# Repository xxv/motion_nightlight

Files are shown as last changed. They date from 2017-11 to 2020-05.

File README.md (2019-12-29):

Motion detector night light
===========================

A light to illuminate your dark hallway on your way to the bathroom.

Ingredients
-----------

### Custom parts
* fully-populated and assembled PCB
* laser-cut wooden housing (`housing/housing_lasercut.scad`), cut from 3mm plywood
* laser-cut or 3D printed front grate (`housing/front_grate.svg`), 1.5mm black acrylic
* laser-cut diffuser holder (`housing/diffuser_holder.scad`), cut from 3mm black acrylic
* 3D printed board holder (`housing/board_holder.scad`)
* 3D printed battery plate (`housing/battery_plate.scad`)

### Vitamins
* 2x M2.5x8 black flat head bolt with washer and nut McMaster: 91294A016,
  90591A270, 93475a196
* 10x M2.2 6.5mm round head screws for sheet metal McMaster: 94997a125
* 3x AA batteries

### Other bits
* Diffuser (`housing/diffuser.scad`) cut from LEE Filters 810 Zircon Diffusion
  1 (or similar)
* Wood glue (+ [clamps](https://github.com/xxv/corner-clamp))
* Super glue
* 2mm-wide double-stick tape or similar

Main Assembly
-------------

1. Assemble PCB. Use M2.5x8 hardware to fasten battery holder to board.
2. Assemble diffuser assembly (see below).
3. Cut out main enclosure.
4. Glue main enclosure together with wood glue. Clamp and wipe off excess glue
   with a damp paper towel.
5. Glue battery plate to battery cover with super glue. (center carefully)
6. Once main enclosure glue is dry, screw board holder to it with M2.2 screws.
7. Screw board to board holder using M2.2 screws.
8. Slide the diffuser assembly into place. It should fit snugly, but not fall out.
9. Put fresh batteries into the night light. Don't put the battery cover on yet.
10. Calibrate the ambient light sensor.
    1. Bringing the night light into a dark room.
    2. Pull out the middle battery.
    3. Holding down both buttons, re-insert the middle battery.
    4. The status LED should blink three times to indicate that the calibration has been saved.

Diffuser Assembly
-----------------

1. Cut out the diffuser stand (4 identical parts) and assemble with super glue.
2. Cut out the diffuser from the Zircon 810 sheet using the diffuser template.
   This material is polyester and can be laser cut if desired.
3. Adhere the diffuser to the diffuser stand using the double-stick tape.
4. Cut out the diffuser decorative grate `front_grate.svg`. Note the
   non-commercial terms for this part in the license at the bottom.
5. Adhere the diffuser decorative grate to the diffuser using 2mm double-stick tape.

License
-------

* The PCB design and associated firmware are licensed under the GPLv3.
* The diffuser grate artwork (`front_grate.svg` and derivatives) is licensed under
  the Creative Commons CC-BY-NC-SA 4.0. If you wish to sell night lights using
  these files, you must use your own design for this one part. Consider this an
  opportunity to make your night light truly your own!
* All of the mechanical parts (housing, board stand, etc.) are available
  licensed under the Creative Commons CC-BY-SA 4.0 license.

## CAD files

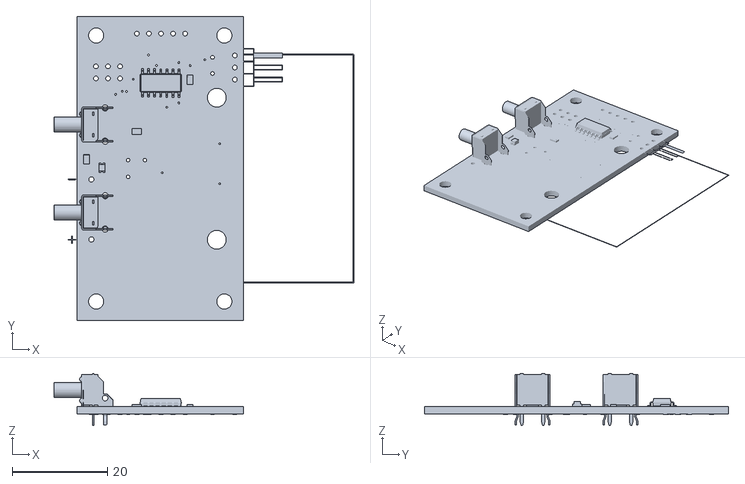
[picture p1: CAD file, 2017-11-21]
board/motion_light.stl
63.1 x 64.0 x 11.0

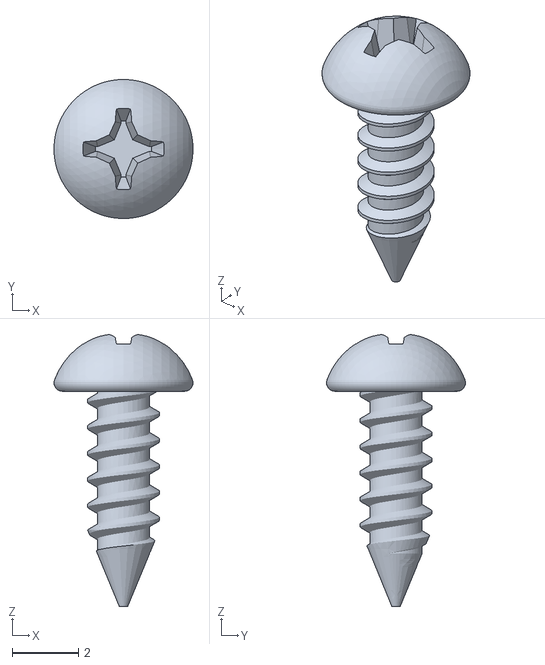
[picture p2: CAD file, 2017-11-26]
housing/m2.2_wood_screw.stl
4.20 x 4.20 x 8.22

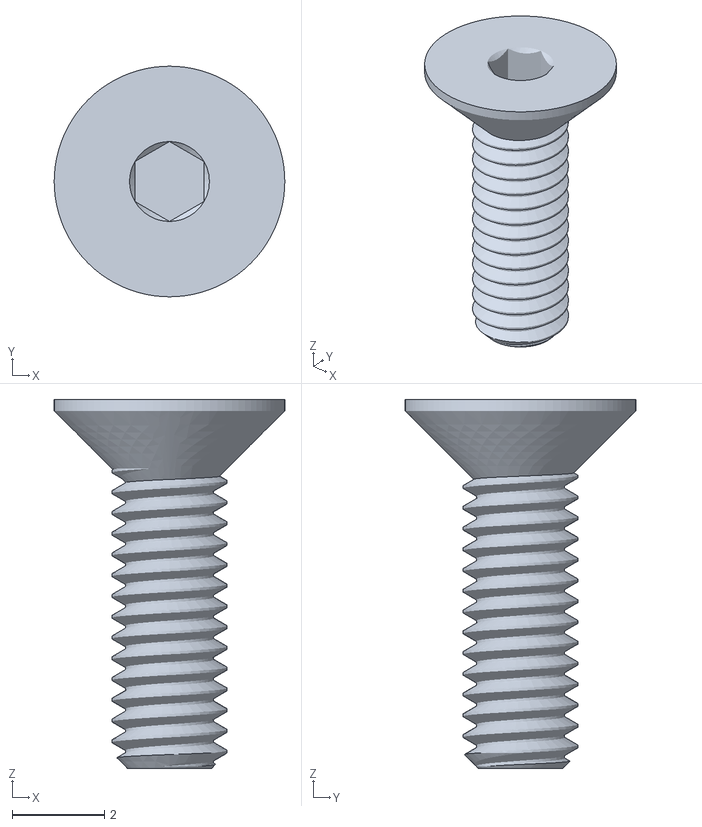
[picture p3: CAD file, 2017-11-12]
housing/m2.5x8_screw.stl
5.00 x 5.00 x 8.00

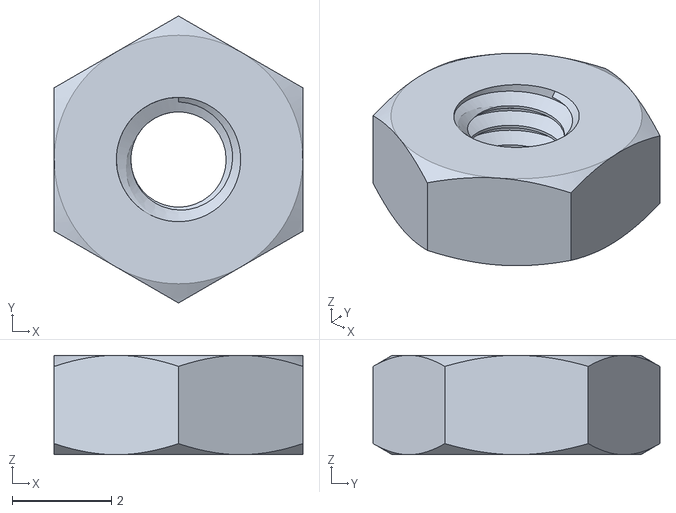
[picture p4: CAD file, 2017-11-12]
housing/m2.5_nut.stl
5.00 x 5.77 x 2.00

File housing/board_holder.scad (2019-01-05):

include <motion_nightlight_housing.scad>;

board_holder(interior_battery);

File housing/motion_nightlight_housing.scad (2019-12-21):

include <boxmaker.scad>;

$fn = 120;
smidge = 0.1;

// main interior volume
interior_battery = [94, 94, 32];
// thickness of the wall material
wall_size = 3.3;
// distance between the top and the board
board_z = 12.5;

// size of the PCB
board_size = [64, 35.0, 1.6];
// Clearance from the wall for the board
board_clearance = 1;
// distance in from the edge of the PCB that the holes are
board_hole_offset = 4;

battery_hole_size = [46, 55];
battery_hole_offset = [0, 3];
battery_finger_size = 15;
// holes to screw plate into the wood
laser_pilot_hole = 1.2/2;

// amount that the board mount overlaps with the wood
overlap = 6;
// how much inset the battery lid rest is from the battery hole
inset = 1;

// width of the plate holding the board
plate_width = board_size[0] + overlap * 2;
// Wood screws that mount the plate to the bottom wall
wood_screws = [
  [battery_hole_size[0]/2 + overlap/2, board_clearance + board_size[1] + overlap/2, 0],
  [battery_hole_size[0]/2 + overlap/2, battery_hole_size[1] + battery_hole_offset[1] + overlap/2, 0],
  [plate_width/2 - overlap/2, overlap/2, 0]
  ];

diffuser_stand_volume = interior_battery;

stand_material = 3;

//////////////////////////////////////////////////////////////////////

*mockup(interior_battery, diffuser_stand_volume, battery_present=1);

/********* laser cut *********/
*enclosure_2d(interior_battery, wall_size);

/********* 3D Print **********/
*board_holder(interior_battery);
*battery_plate(interior_battery);
*grate();
*diffuser_stand_print(diffuser_stand_volume);
  // This can be a knife template for cutting the diffuser material
*diffuser(diffuser_stand_volume, 2);

//////////////////////////////////////////////////////////////////////

module mockup(interior, stand_volume, battery_present) {
  translate([interior[0]/2 - board_size[0]/2, board_clearance, 0])
    electronics(battery_present);
  enclosure_with_design(interior, stand_volume);
}

module diffuser_stand_print(stand_volume) {
  spacing = 1;

  diffuser_stand_leg([stand_volume.x, stand_volume.z], stand_material);
  translate([0, 1 * (stand_volume.z + spacing)])
      diffuser_stand_leg([stand_volume.x, stand_volume.z], stand_material);

  translate([0, 2 * (stand_volume.z + spacing)])
    diffuser_stand_leg([stand_volume.y, stand_volume.z], stand_material);

  translate([0, 3 * (stand_volume.z + spacing)])
    diffuser_stand_leg([stand_volume.y, stand_volume.z], stand_material);
}

module enclosure_with_design(interior, stand_volume) {
  translate([0, 0, -(interior[2] - board_z)]) {
    translate([0, 0, stand_volume[2]])
      diffuser_and_grate(stand_volume);

    color([0.5, 0.5, 0.5]) {
      board_holder(interior);
      battery_plate(interior);
    }

    color("SaddleBrown", alpha=1)
      enclosure_3d(interior, wall_size);
  }
}

module diffuser_and_grate(inner_size) {
  diffuser_thickness = 0.1;

  translate([0, 0, diffuser_thickness + 0.01])
    color(c=[0.2, 0.2, 0.2])
      grate();

  // diffuser
  color(c=[0.95, 0.95, 0.95, 1])
    diffuser(inner_size, diffuser_thickness);

  color(c=[0.2, 0.2, 0.2])
      diffuser_stand(inner_size);
}

module diffuser_stand(inner_size) {
  material = stand_material;

  rotate([-90, 0, 0])
    linear_extrude(height=material)
      diffuser_stand_leg([inner_size.x, inner_size.z], material);

  translate([0, inner_size.y, 0])
    rotate([-90, 0, 270])
      linear_extrude(height=material)
        diffuser_stand_leg([inner_size.y, inner_size.z], material);

  translate([inner_size.x, inner_size.y, 0])
    rotate([-90, 0, 180])
      linear_extrude(height=material)
        diffuser_stand_leg([inner_size.x, inner_size.z], material);

  translate([inner_size.x, 0, 0])
    rotate([-90, 0, 90])
      linear_extrude(height=material)
        diffuser_stand_leg([inner_size.y, inner_size.z], material);
}

module diffuser_stand_leg(bounds, material) {
  leg = 8;
  top = 5;

  difference() {
    square(bounds);
    translate([leg, top])
      square([bounds.x - leg * 2, bounds.y - top]);

    translate([0, bounds.y/3])
      square([material, bounds.y/3]);

    translate([bounds.x - material, 0])
      square([material, bounds.y/3]);

    translate([bounds.x - material, bounds.y * (2/3)])
      square([material, bounds.y/3]);
  }
}

module grate() {
  linear_extrude(height=1)
    import("front_grate.dxf");
}

module diffuser(inner_size, thickness=0.1) {
  difference() {
    cube(inner_size + [0, 0, -(inner_size[2] - thickness)]);
    translate([inner_size[0]/2, 13.5, -1])
      cylinder(r=11, h=thickness + 2);
  }
}

module board_holder(interior) {
  thickness = 1;
  stand_width = 6;
  battery_hole = [battery_hole_size[0] - inset * 2, battery_hole_size[1] - inset * 2, thickness + 1];
  board_screw_hole = 0.75;
  plate_screw_hole = 2.5;
  z_height = interior[2] - board_z - board_size[2]/2;

  screw_standoff = 2.5;

#  translate([interior[0]/2, 0, screw_standoff + 1])
      for (m = [0 : 1 : 1])
        mirror([m, 0, 0])
          for (screw = wood_screws)
            translate(screw)
              import("m2.2_wood_screw.stl");

  corner_r = overlap/2;
  overlap_rounded = overlap - corner_r;
  plate_width_rounded = plate_width - corner_r - overlap/2;

  // main plate
  intersection() {
    difference() {
      union() {
        minkowski() {
          union() {
            translate([interior[0]/2 - battery_hole_size[0]/2 - overlap_rounded, 0, 0])
              cube([battery_hole_size[0] + (overlap_rounded) * 2, battery_hole_size[1] + battery_hole_offset[1] + overlap_rounded, thickness]);

            translate([interior[0]/2 - plate_width_rounded/2, 0, 0])
              cube([plate_width_rounded, board_size[1] + board_clearance + overlap_rounded, thickness]);
            }
            cylinder(r=corner_r, h=0.0001);
        }

        // Screw stands
        translate([interior[0]/2, 0, 1])
            for (m = [0 : 1 : 1])
              mirror([m, 0, 0])
                for (screw = wood_screws)
                  translate(screw)
                    cylinder(r=overlap/2, h=screw_standoff);
      }

      // Battery hole
      translate(battery_hole_offset)
        translate([interior[0]/2 - battery_hole[0]/2, inset, -0.5])
          cube(battery_hole);

      // Screw holes
      translate([interior[0]/2, 0, -1])
        for (m = [0 : 1 : 1])
          mirror([m, 0, 0])
            for (screw = wood_screws)
              translate(screw)
                cylinder(r=plate_screw_hole/2, h=10);
    }
    cube(interior);
  }

  // board stands
  translate([interior[0]/2, board_clearance + board_size[1]/2, 0])
    for (m = [0 : 1 : 1])
      mirror([m, 0, 0])
        translate([board_size[0]/2 - stand_width - 1, -board_size[1]/2, 0])
          difference() {
            cube([stand_width, board_size[1], z_height]);

            translate([stand_width/2, board_hole_offset, z_height - 4.9])
              cylinder(r=board_screw_hole, h=5);

            translate([stand_width/2, board_size[1] - board_hole_offset, z_height - 4.9])
              cylinder(r=board_screw_hole, h=5);
          }
}

module battery_plate(interior) {
  battery_plate_wall = [3, 3, 0];
  inset_for_mating = 0.3;
  extra_inset = [inset * 2 + inset_for_mating, inset * 2 + inset_for_mating, 0];
  wall_thickness = 1.5;
  plate_thickness = 0.5;
  battery_hole = [battery_hole_size[0],
                  battery_hole_size[1],
                  wall_thickness + plate_thickness] - extra_inset;

      translate(battery_hole_offset)
        translate([interior[0]/2 - battery_hole_size[0]/2, 0, 0] + extra_inset/2)
          difference() {
            cube(battery_hole);
            translate(battery_plate_wall/2 - [0, 0, -plate_thickness])
              cube(battery_hole - (battery_plate_wall + [0, 0, -3]));
            translate([(battery_hole_size[0] - extra_inset[0])/2, battery_hole_size[1] - extra_inset[1]/2, -1])
              cylinder(d=battery_finger_size, h=wall_thickness + plate_thickness + 2);
            translate([-smidge, battery_hole.y, 0])
              rotate([10, 0, 0])
              cube([battery_hole.x + 2 * smidge, 1, battery_hole.z + 1]);
          }
}

module back_face(box_inner, thickness, tabs) {
  screw_hole_spacing = 70;
  screw_size = 3;
  screw_head_size = screw_size + 3;

  difference() {
    side_a(box_inner, thickness, tabs);
    // Battery hole
    translate(-battery_hole_offset)
      translate([box_inner[0]/2 - battery_hole_size[0]/2,
                 box_inner[1] - battery_hole_size[1]])
        difference() {
          square(battery_hole_size);

          difference() {
            translate([smidge, smidge])
              square(battery_hole_size - [smidge * 2, smidge * 2]);

              translate([battery_hole_size[0]/2, 0])
              circle(d=battery_finger_size);
          }
        }

    // Screw holes
    translate([box_inner[0]/2 - screw_hole_spacing/2, screw_head_size * 2, 0])
      rotate([180])
        screw_slot_2d(screw_head_size, screw_size, screw_head_size);
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

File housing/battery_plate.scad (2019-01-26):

include <motion_nightlight_housing.scad>;

battery_plate(interior_battery);

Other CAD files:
housing/front_grate.dxf
housing/diffuser.scad
housing/boxmaker.scad
housing/diffuser_stand.scad
housing/housing_lasercut.scad
housing/mockup.scad
housing/vertical_stand.scad

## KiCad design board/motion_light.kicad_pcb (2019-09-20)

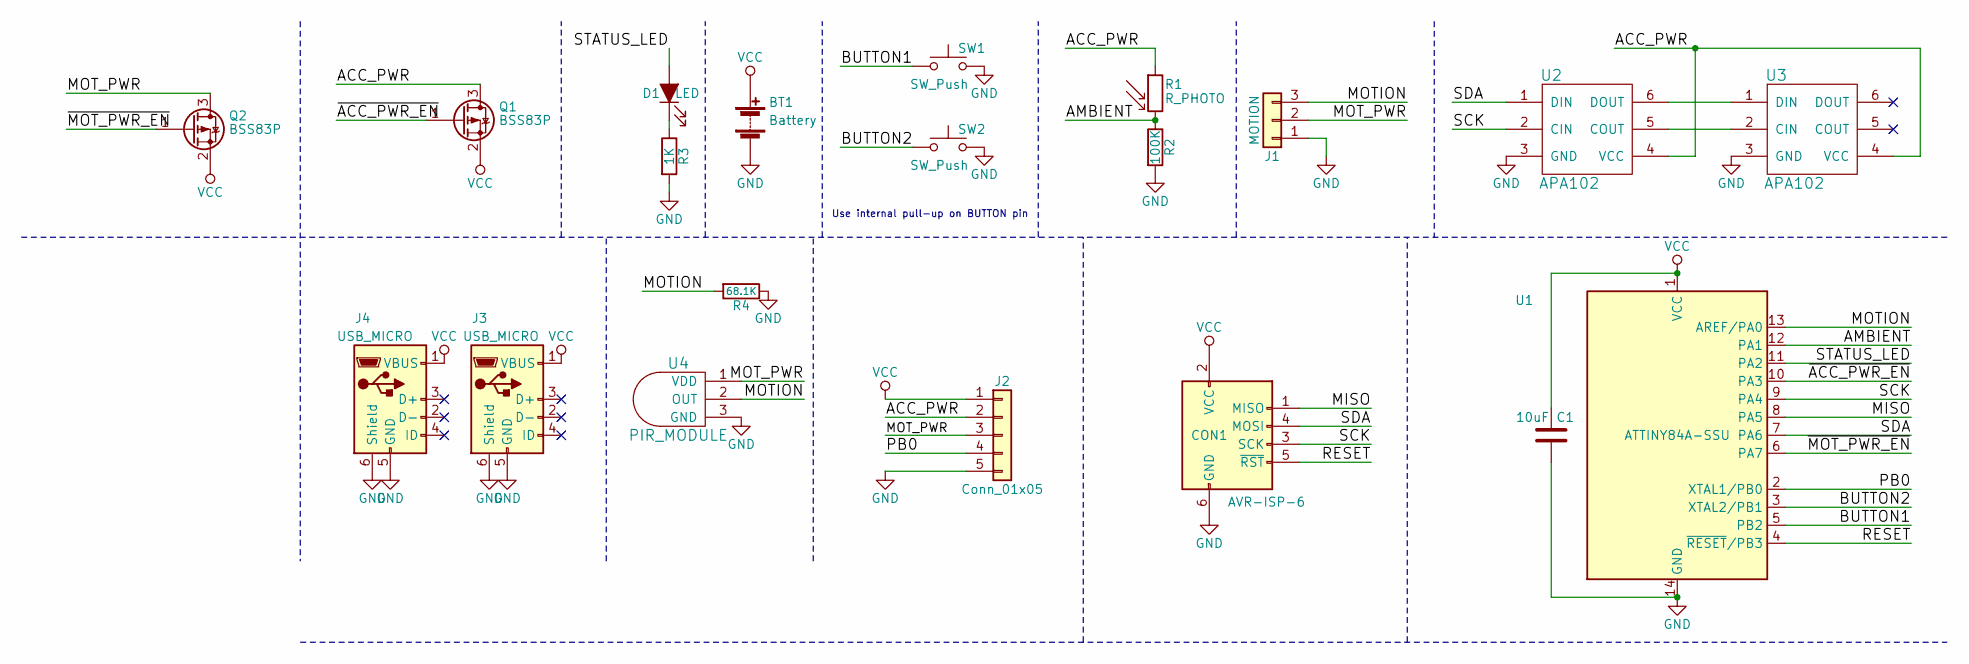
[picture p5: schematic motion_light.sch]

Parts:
BT1: Battery; Keystone_2464_3xAA; MPN 2464
C1: 10uF; C_0805_2012Metric_Pad1.15x1.40mm_HandSolder; MPN CL21A106KQCLRNC
CON1: AVR-ISP-6; PinHeader_2x03_P2.54mm_Vertical; MPN M20-9980345
D1: LED; LED_0805_2012Metric_Pad1.15x1.40mm_HandSolder
J1: MOTION; PinHeader_1x03_P2.54mm_Horizontal; MPN PRPC040SBAN-M71RC
J2: Conn_01x05; PinHeader_1x05_P2.54mm_Vertical
J3, J4: USB_MICRO; USB_Micro-B_Molex-105017-0001
Q1, Q2: BSS83P; SOT-23; MPN BSS83PH6327XTSA1
R1: R_PHOTO; R_LDR_5.1x4.3mm_P3.4mm_Vertical; MPN PDV-P8103
R2: 100K; R_0805_2012Metric_Pad1.15x1.40mm_HandSolder; MPN RNCP0805FTD10K0
R3: 1K; R_0805_2012Metric_Pad1.15x1.40mm_HandSolder; MPN RNCP0805FTD1K00
R4: 68.1K; R_0805_2012Metric_Pad1.15x1.40mm_HandSolder; MPN RNCP0805FTD68K1
SW1, SW2: SW_Push; SW_Tactile_SPST_Angled_PTS645Vx83-2LFS; MPN PTS645VL83-2 LFS
U1: ATTINY84A-SSU; SOIC-14_3.9x8.7mm_P1.27mm; MPN ATTINY84A-SSUR
U2, U3: APA102; APA102_hand_solder; MPN SK9822
U4: PIR_MODULE; PaPIR_PIR_SENSOR; MPN EKMC1604112

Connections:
/ACC_PWR: J2.2, Q1.3 (D), R1.1, U2.4 (VCC), U3.4 (VCC)
/AMBIENT: R1.2, R2.1, U1.12 (PA1)
/BUTTON1: SW1.1, U1.5 (PB2)
/BUTTON2: SW2.1, U1.3 (XTAL2/PB1)
/MISO: CON1.1 (MISO), U1.8 (PA5)
/MOTION: J1.3, R4.2, U1.13 (AREF/PA0), U4.2 (OUT)
/MOT_PWR: J1.2, J2.3, Q2.3 (D), U4.1 (VDD)
/PB0: J2.4, U1.2 (XTAL1/PB0)
/RESET: CON1.5 (~RST), U1.4 (~RESET~/PB3)
/SCK: CON1.3 (SCK), U1.9 (PA4), U2.2 (CIN)
/SDA: CON1.4 (MOSI), U1.7 (PA6), U2.1 (DIN)
/STATUS_LED: D1.2 (A), U1.11 (PA2)
/~ACC_PWR_EN: Q1.1 (G), U1.10 (PA3)
/~MOT_PWR_EN: Q2.1 (G), U1.6 (PA7)
GND: BT1.2 (-), C1.2, CON1.6 (GND), J1.1, J2.5, J3.5 (GND), J3.6 (Shield), J4.5 (GND), J4.6 (Shield), R2.2, R3.2, R4.1, SW1.2, SW2.2, U1.14 (GND), U2.3 (GND), U3.3 (GND), U4.3 (GND)
unnamed: D1.1 (K), R3.1
unnamed: U2.5 (COUT), U3.2 (CIN)
unnamed: U2.6 (DOUT), U3.1 (DIN)
VCC: BT1.1 (+), C1.1, CON1.2 (VCC), J2.1, J3.1 (VBUS), J4.1 (VBUS), Q1.2 (S), Q2.2 (S), U1.1 (VCC)

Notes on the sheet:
Use internal pull-up on BUTTON pin

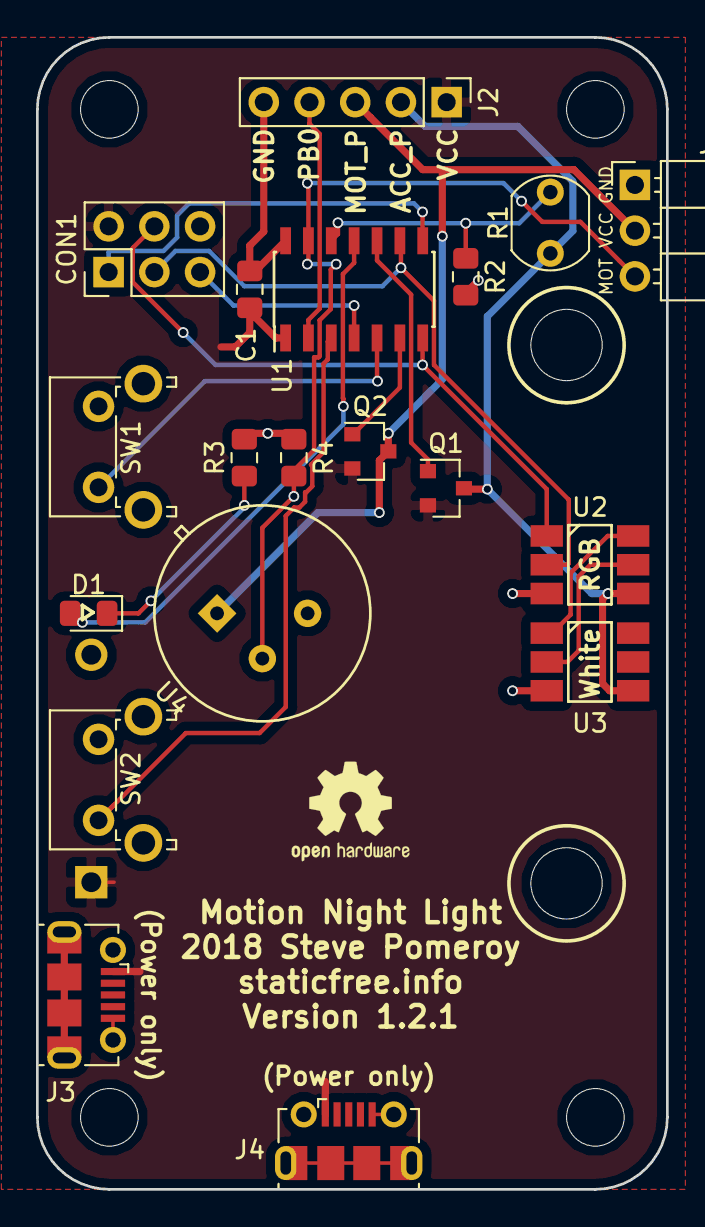
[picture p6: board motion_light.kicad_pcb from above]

Board: 2 copper layers, 35.0 x 64.0 mm, 20 parts (1 on the bottom side), 19 nets.

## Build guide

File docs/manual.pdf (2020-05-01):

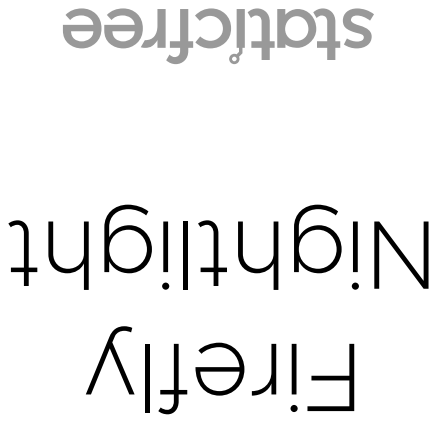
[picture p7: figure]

## Specifications

Sensors: ambient light, motion (PIR)

Color modes: amber, white (2700K), reddish white, blueish white, moonlight, red, yellow, green, teal, blue, purple, random.
5 brightness levels.

Light source: LED, RGBW (2700K white)

Battery: 3×AA; expected battery life: 6+mo.

Dimensions: 100×100×38mm (4"×4"×1.5")

Support email: steve@staticfree.info

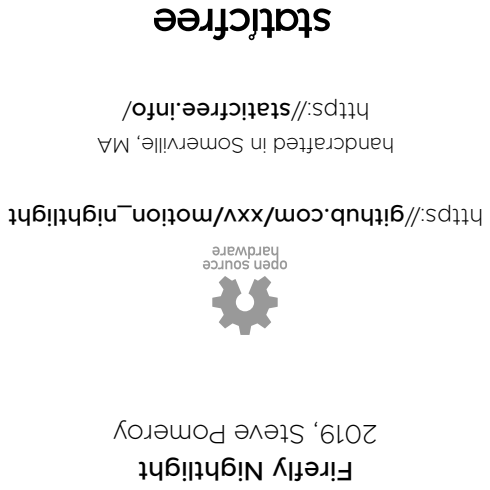
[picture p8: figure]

Usage
Your Firefly Nightlight will light up when it's dark and senses motion. Press the rainbow button to cycle between color modes. Press the brightness button to cycle between the five brightness levels.

Mounting
To place the nightlight on a flat surface, place the nightlight in the included black vertical stand.
To mount on a wall, use the included Command Strips or hang it on the cutouts (7cm/2.8in spacing). To use the Command Strips, see the online instructions: http://bit.ly/2rBwh8o

Darkness Sensor Recalibration
Your nightlight has been calibrated to sense a dark room. If you'd like to recalibrate it, do the following:
1. Put nightlight in an environment that has the brightness you desire.
2. Remove one battery.
3. Hold down both buttons and re-insert battery. Release buttons.
4. A small amber light behind the motion sensor will blink 3 times to let you know that it has been calibrated successfully.

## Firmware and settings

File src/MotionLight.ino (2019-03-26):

#include <avr/power.h>
#include <avr/sleep.h>
#include <EEPROM.h>
#include <FastLED.h>
#include <JC_Button.h>
#include "apa102_dim.h"

const static bool DEBUG_ACCESSORY_POWER = false;
const static bool DEBUG_AMBIENT         = false;
const static bool DEBUG_MOTION          = false;
const static bool DEBUG_SLEEPING        = false;
const static bool DEBUG_WATCHDOG        = false;

struct LightColors {
  long rgb;
  long white;
};

struct SettingsData {
  uint8_t brightness_level_idx;
  uint8_t palette_idx;
  int ambient_level;
};

const static uint8_t BRIGHTNESS_LEVELS[] = { 2, 4, 8, 16, 31 };

const static uint8_t SETTINGS_ADDRESS = 0;

const static long COLOR_MODE_RANDOM = 0xFFFFFE;

const struct LightColors PALETTES[] = {
  { 0xFFBF00, 0x000000 }, // amber
  { 0x000000, 0x555555 }, // white
  { 0x000000, 0xAAAAAA }, // bright white
  { 0x000000, 0xFFFFFF }, // max white
  { 0xFF0000, 0x555555 }, // white with red
  { 0x0000FF, 0x555555 }, // white with blue
  { 0xA0A0FF, 0x000000 }, // moonlight
  { 0xFF0000, 0x000000 }, // red
  { 0xFFFF00, 0x000000 }, // yellow
  { 0x00FF00, 0x000000 }, // green
  { 0x00FFFF, 0x000000 }, // teal
  { 0x0000FF, 0x000000 }, // blue
  { 0xFF00FF, 0x000000 }, // purple
  { 0x000000, COLOR_MODE_RANDOM }, // show a random color, incl. white
};

const static int PIN_MOTION      = PIN_A0;
const static int PIN_AMBIENT     = A1;
const static int PIN_STATUS_LED  = PIN_A2;
const static int PIN_ACC_PWR_DIS = PIN_A3;
const static int PIN_MOT_PWR_DIS = PIN_A7;
const static int PIN_BUTTON_1    = PIN_B2;
const static int PIN_BUTTON_2    = PIN_B1;
const static int PIN_SCK         = 4;
const static int PIN_SDA         = 6;

const static int NUM_LEDS       = 2;
const static int RGB_LED        = 0;
const static int WHITE_LED      = 1;

const static uint8_t DEEP_SLEEP_TIMEOUT_COUNT   = 5; // number of watchdog wakes
const static unsigned long TIMEOUT_MS           = 5000;
const static long SETTING_TIMEOUT_MS            = 5000;
const static long BRIGHTNESS_SETTING_TIMEOUT_MS = 1500;
const static long LONG_PRESS_MS                 = 1000;

const static int AMBIENT_HYSTERESIS = 10;

// transient state
unsigned long on_time = 0;
unsigned long brightness_setting_timeout = 0;
CRGBArray<NUM_LEDS> leds;
CRGBArray<NUM_LEDS> leds_prefade;

uint8_t deep_sleep_countdown = 0;
uint8_t fade_value = 0;
uint8_t prev_fade_value = 0;
bool motion = false;
bool is_dark_enough = false;
bool light_on = false;
bool update_color = true;
bool woke_from_watchdog = false;

int ambient_darkness_level = 0;
uint8_t brightness_idx = 0;
uint8_t palette_idx = 0;

/**
 * sleeping = low power, wake via motion
 * deep_sleeping = lowest power, wake via being dark
 * running = light is fading on/off/steady on
 */
enum Mode { sleeping, deep_sleeping, running, setting };

Mode mode = running;

APA102Controller_WithBrightness<PIN_SDA, PIN_SCK, BGR>ledController;

Button button1(PIN_BUTTON_1);
Button button2(PIN_BUTTON_2);

ISR (PCINT0_vect) {
  // Don't need to do anything, just wake up.
}

ISR (PCINT1_vect) {
  // Don't need to do anything, just wake up.
}

ISR (WDT_vect) {
  MCUSR = 0x00;
  WDTCSR |= _BV(WDE) | _BV(WDCE);
  WDTCSR = 0x00; // disable watchdog

  if (DEBUG_WATCHDOG) {
    digitalWrite(PIN_STATUS_LED, HIGH);
  }

  woke_from_watchdog = true;
}

void watchdog_enable() {
  if (DEBUG_WATCHDOG) {
    digitalWrite(PIN_STATUS_LED, LOW);
  }

  bitSet(WDTCSR, WDIE);           // watchdog triggers an interrupt
  WDTCSR |= _BV(WDP0) | _BV(WDP1) | _BV(WDP2); // trigger every 2 seconds

  bitSet(WDTCSR, WDE); // enable watchdog
}

void set_motion_powered(const bool is_powered) {
  digitalWrite(PIN_MOT_PWR_DIS, !is_powered);
}

void set_accessory_powered(const bool is_powered) {
  digitalWrite(PIN_ACC_PWR_DIS, !is_powered);

  if (DEBUG_ACCESSORY_POWER) {
    digitalWrite(PIN_STATUS_LED, is_powered);
  }
}

void update_deep_sleep_monitoring() {
  if (is_dark_enough) {
    deep_sleep_countdown = 0;
  } else {
    deep_sleep_countdown++;
  }
}

bool should_deep_sleep() {
  return deep_sleep_countdown >= DEEP_SLEEP_TIMEOUT_COUNT;
}

/**
 * Enable Pin Change Interrupt on given pin number.
 */
void pciSetup(byte pin) {
  bitSet(*digitalPinToPCMSK(pin), digitalPinToPCMSKbit(pin)); // enable pin
  bitSet(*digitalPinToPCICR(pin), digitalPinToPCICRbit(pin)); // enable interrupt
}

/**
 * Enable sleep mode and turn on pin change interrupt
 */
void sleep_now(bool deep_sleep) {
  redraw_lights();

  woke_from_watchdog = false;
  watchdog_enable();

  set_accessory_powered(false);
  set_motion_powered(!deep_sleep);

  if (deep_sleep) {
    deep_sleep_countdown = 0;
  } else {
    pciSetup(PIN_MOTION);
  }

  pciSetup(PIN_BUTTON_1);
  pciSetup(PIN_BUTTON_2);

  setMode(deep_sleep ? deep_sleeping : sleeping);
  set_sleep_mode(SLEEP_MODE_PWR_DOWN);
  sleep_enable();

  if (DEBUG_SLEEPING) {
    digitalWrite(PIN_STATUS_LED, LOW);
  }

  bitClear(ADCSRA, ADEN); // disable ADC

  // -.- zzz...
  sleep_mode();

  // !! O.O
  sleep_disable();

  bitSet(ADCSRA, ADEN); // re-enable ADC

  if (DEBUG_SLEEPING) {
    digitalWrite(PIN_STATUS_LED, HIGH);
  }

  disable_pc_interrupts();
  interrupts();
}

void disable_pc_interrupts(byte pin) {
  bitClear(*digitalPinToPCICR(pin), digitalPinToPCICRbit(pin));
}

void disable_pc_interrupts() {
  disable_pc_interrupts(PIN_MOTION);
  disable_pc_interrupts(PIN_BUTTON_1);
  disable_pc_interrupts(PIN_BUTTON_2);
}

void load_settings() {
  SettingsData data;
  EEPROM.get(SETTINGS_ADDRESS, data);

  set_brightness_level(data.brightness_level_idx);
  set_palette(data.palette_idx);
  ambient_darkness_level = data.ambient_level;
}

void save_settings() {
  SettingsData data = {
    brightness_idx,
    palette_idx,
    ambient_darkness_level
  };

  EEPROM.put(SETTINGS_ADDRESS, data);
}

void cycle_brightness_level() {
  set_brightness_level(brightness_idx + 1);
}

void set_brightness_level(uint8_t index) {
  brightness_idx = index %
      (sizeof(BRIGHTNESS_LEVELS)/sizeof(BRIGHTNESS_LEVELS[0]));

  ledController.setAPA102Brightness(BRIGHTNESS_LEVELS[brightness_idx]);
}

void cycle_palette() {
  set_palette(palette_idx + 1);
}

void set_palette(uint8_t index) {
  palette_idx = index % (sizeof(PALETTES)/sizeof(PALETTES[0]));
  set_leds_prefade();
}

void set_leds_prefade() {
  if (PALETTES[palette_idx].white == COLOR_MODE_RANDOM) {
    if (random8(15) == 0) {
      leds_prefade[RGB_LED] = 0x000000;
      leds_prefade[WHITE_LED] = 0x555555;
    } else {
      leds_prefade[RGB_LED] = CHSV(random8(), 255, 255);
      leds_prefade[WHITE_LED] = 0x000000;
    }
  } else {
    leds_prefade[RGB_LED] = PALETTES[palette_idx].rgb;
    leds_prefade[WHITE_LED] = PALETTES[palette_idx].white;
  }

  update_color = true;
}

void led_test() {
  digitalWrite(PIN_STATUS_LED, HIGH);
  leds[WHITE_LED] = CRGB(0, 0, 0);
  leds[RGB_LED] = CRGB(20, 0, 0);
  FastLED.show();
  delay(500);
  leds[RGB_LED] = CRGB(0, 20, 0);
  FastLED.show();
  delay(500);
  leds[RGB_LED] = CRGB(0, 0, 20);
  FastLED.show();
  delay(500);
  leds[RGB_LED] = CRGB(0, 0, 0);
  leds[WHITE_LED] = CRGB(20, 0, 0);
  FastLED.show();
  delay(500);
  leds[RGB_LED] = CRGB(0, 0, 0);
  leds[WHITE_LED] = CRGB(0, 0, 0);
  FastLED.show();
  digitalWrite(PIN_STATUS_LED, LOW);
}

int analogReadAverage(uint8_t pin, uint8_t count) {
  int sum = 0;

  for (uint8_t i = 0; i < count; i++) {
    sum += analogRead(pin);
  }

  return sum / count;
}

void setup() {
  button1.begin();
  button2.begin();
  pinMode(PIN_MOTION, INPUT);
  pinMode(PIN_AMBIENT, INPUT);
  pinMode(PIN_STATUS_LED, OUTPUT);
  pinMode(PIN_ACC_PWR_DIS, OUTPUT);
  pinMode(PIN_MOT_PWR_DIS, OUTPUT);
  FastLED.addLeds((CLEDController*) &ledController, leds, NUM_LEDS);

  set_accessory_powered(true);
  set_motion_powered(true);
  led_test();

  load_settings();

  if (button1.isPressed() && button2.isPressed()) {
    // a delay to ensure there is no light from the white LED
    delay(100);
    ambient_darkness_level = analogReadAverage(PIN_AMBIENT, 10);
    save_settings();

    digitalWrite(PIN_STATUS_LED, LOW);
    delay(250);
    digitalWrite(PIN_STATUS_LED, HIGH);
    delay(250);
    digitalWrite(PIN_STATUS_LED, LOW);
    delay(250);
    digitalWrite(PIN_STATUS_LED, HIGH);
    delay(250);
    digitalWrite(PIN_STATUS_LED, LOW);
    delay(250);
    digitalWrite(PIN_STATUS_LED, HIGH);
    delay(250);
  }

  digitalWrite(PIN_STATUS_LED, LOW);
}

void handleSettingMode() {
  bool buttonPressed = false;

  if (button1.wasPressed()) {
    cycle_brightness_level();
    buttonPressed = true;
    brightness_setting_timeout = millis();
  } else if (button2.wasPressed()) {
    cycle_palette();
    buttonPressed = true;
  } else if (button1.pressedFor(LONG_PRESS_MS)) {
    set_brightness_level(0);
    buttonPressed = true;
  } else if (button2.pressedFor(LONG_PRESS_MS)) {
    set_palette(0);
    buttonPressed = true;
  }

  // animate the palette to indicate random mode
  if (PALETTES[palette_idx].white == COLOR_MODE_RANDOM &&
      (millis() - brightness_setting_timeout) > BRIGHTNESS_SETTING_TIMEOUT_MS) {
    EVERY_N_MILLIS(333) {
      set_leds_prefade();
    }
  }

  if (buttonPressed) {
    light_on = true;
    on_time = millis();
  }

  if ((millis() - on_time) > SETTING_TIMEOUT_MS) {
    save_settings();
    setMode(running);
  }
}

void check_buttons() {
  if (button1.pressedFor(LONG_PRESS_MS) && button2.pressedFor(LONG_PRESS_MS)) {
    led_test();
  } else if (button1.wasPressed() || button2.wasPressed()) {
    motion = true;
    fade_value = 255;
    update_color = true;
    setMode(setting);
  }
}

void handleRunningMode() {
  if (motion) {
    on_time = millis();

    if (!light_on) {
      set_leds_prefade();
    }

    light_on = true;
  }

  if (!motion && light_on && (millis() - on_time) > TIMEOUT_MS) {
    light_on = false;
  }
}

void redraw_lights() {
  if (update_color) {
    leds = leds_prefade;

    leds[RGB_LED].nscale8_video(fade_value);
    leds[WHITE_LED].nscale8_video(fade_value);

    update_color = false;
  }

  FastLED.show();
}

void update_ambient_level() {
  if (is_dark_enough) {
    is_dark_enough = analogRead(PIN_AMBIENT) <=
                     (ambient_darkness_level + AMBIENT_HYSTERESIS);
  } else {
    is_dark_enough = analogRead(PIN_AMBIENT) <=
                     (ambient_darkness_level - AMBIENT_HYSTERESIS);
  }
}

void manage_power() {
  if (mode == running) {
    if (!light_on && fade_value == 0) {
      sleep_now(false);
    }
  } else if (mode == deep_sleeping) {
    sleep_now(!is_dark_enough);
  } else if (mode == sleeping) {
    sleep_now(should_deep_sleep());
  }
}

void setMode(Mode newMode) {
  if (mode != newMode) {
    switch (newMode) {
      case deep_sleeping:
        // fall through
      case sleeping:
        // fall through
      case running:
        if (mode == setting) {
          digitalWrite(PIN_STATUS_LED, LOW);
        }
        set_motion_powered(true);
        break;
      case setting:
        digitalWrite(PIN_STATUS_LED, HIGH);
        break;
    }
    mode = newMode;
  }
}

void loop() {
  EVERY_N_MILLIS(10) {
    button1.read();
    button2.read();

    set_accessory_powered(true);
    motion = digitalRead(PIN_MOTION);
    update_ambient_level();

    switch (mode) {
      case sleeping:
        if (woke_from_watchdog) {
          update_deep_sleep_monitoring();
        }
        // fall through
      case deep_sleeping:
        if (motion && is_dark_enough) {
          setMode(running);
          handleRunningMode();
        }
        check_buttons();
        break;
      case running:
        check_buttons();
        handleRunningMode();
        break;
      case setting:
        handleSettingMode();
        break;
    }
  }

  if (DEBUG_AMBIENT) {
    digitalWrite(PIN_STATUS_LED, is_dark_enough);
  }

  if (DEBUG_MOTION) {
    digitalWrite(PIN_STATUS_LED, motion);
  }

  EVERY_N_MILLIS(2) {
    prev_fade_value = fade_value;

    if (light_on) {
      fade_value = qadd8(fade_value, 2);
    } else {
      fade_value = qsub8(fade_value, 1);
    }

    if (prev_fade_value != fade_value) {
      update_color = true;
    }
  }

  redraw_lights();

  manage_power();

  delay(1);
}

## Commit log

2016-03-09 Add a hack in to set brightness using APA102 global brightness
    This seems the only way to get the LED dim enough
2016-03-11 Add housing
    This revision has not been printed as of this commit, so tolerances may
    need to be tweaked.
    [motion_nightlight_housing.scad, motion_nightlight_housing_bottom.stl, motion_nightlight_housing_top.stl]
2017-09-19 First pass at basic motion + LEDs
2017-10-18 Add first pass at board
    [motion_light.kicad_pcb, motion_light.sch]
2017-10-30 Schematic revisions
    * Add BoM details
    * Add pull-down resistor on motion detector module
    * Change GPIO header to 1x5
    [motion_light.sch]
2017-11-12 Add real parts to housing design
    [m2.5_nut.stl, m2.5x8_screw.stl, metal mesh design.dxf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]
2017-11-12 Rework board; add mesh design
    * Make board an even size
    * Adjust position of motion detector
    * Improve model of PIR sensor
    [metal mesh design.dxf, motion_light.kicad_pcb, motion_light.stl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]
2017-11-21 Move ambient light sensor; center buttons and status LED
    * Improve silk documentation
    [motion_light.kicad_pcb, motion_light.stl]
2017-11-21 Add more silk docs
    [motion_light.kicad_pcb]
2017-11-26 Use boxmaker library to generate enclosure
    [motion_nightlight_housing.scad]
2017-11-26 Tidy up photo resistor mockup
    [motion_nightlight_housing.scad]
2017-11-26 Add screw slots
    [motion_nightlight_housing.scad]
2017-11-26 Correct parts in BoM
    [motion_light.sch]
2017-11-26 Add board mounting bracket
    [motion_nightlight_housing.scad]
2017-11-26 Add wood screw model
    [m2.2_wood_screw.stl]
2017-11-26 Add pretty rounded corners to mounting plate; tidy defs
    [motion_nightlight_housing.scad]
2017-11-27 Redesign diffuser to be mounted on a stand-off
    [metal mesh design.dxf, motion_nightlight_housing.scad]
2017-11-27 Tweak screw holes
    [motion_nightlight_housing.scad]
2017-12-02 Add wings to firefly design
    [metal mesh design.dxf]
2017-12-04 Thin and simplify wings in design
    [metal mesh design.dxf]
2017-12-06 Fix PIR sensor footprint
    [motion_light.kicad_pcb]
2017-12-06 Update pins for new board
2017-12-06 Fix PIR orientation; update PIR silk; add more silk labels
    [motion_light.kicad_pcb]
2017-12-09 Add basic button support
2017-12-17 Use all three elements in white LED
2017-12-17 Fix power-off bug
2017-12-17 Better handle button presses in sleep mode
2017-12-17 Add ambient light sensor support
2017-12-28 Add decoupling cap
    [motion_light.kicad_pcb, motion_light.sch]
2017-12-28 Rotate LEDs to make them closer together and easier to solder
    [motion_light.kicad_pcb]
2018-01-06 Add basic power management
2018-03-02 Schematic changes of unknown variety
    [motion_light.kicad_pcb, motion_light.sch]
2018-03-02 Moar schematic changes
    [motion_light.kicad_pcb, motion_light.sch]
2018-03-02 Wall thickness to 3.3mm
    [motion_nightlight_housing.scad]
2018-03-03 Make it easier to switch between 2d/3d in design
    [motion_nightlight_housing.scad]
2018-03-03 Add battery plate holder
    [motion_nightlight_housing.scad]
2018-03-03 Offset bottom parts for easier cutting
    [motion_nightlight_housing.scad]
2018-08-02 Switch to KiCAD 5; add USB plugs
    * Update footprints and library symbols to KiCAD 5
    * Add optional USB plugs to power directly
    [motion_light.kicad_pcb, motion_light.sch]
2018-08-14 Fix broken pin mappings; add accessory powerdown
    [MotionLight.ino]
2018-08-14 Add watchdog timer
2018-08-14 Use global brightness for global dimming
    Because the SK9822s have non-terrible global brightness control, this
    can now be used for its intended function. If using APA102s, this should
    be reverted.
    [MotionLight.ino]
2018-08-15 Add hysteresis function to ambient light sensor
2018-08-19 Fiddly board updates
    [motion_light.kicad_pcb]
2018-08-20 Add separate power control for motion detector power
    [motion_light.kicad_pcb, motion_light.sch]
2018-08-20 Shutdown ADC to save power
2018-09-11 Add support for motion detector power down
2018-09-11 Switch to updated button library
2018-09-11 Allow on-board calibration of darkness sensor
2018-10-27 Increase screw overlap to improve print quality.
    [motion_nightlight_housing.scad]
2018-10-27 Make more properly parametric
    [motion_nightlight_housing.scad]
2018-11-23 Rotate motion detector to work with wall-oriented detector
    [motion_light.kicad_pcb]
2018-11-25 Update board BoM; upgrade symbols
    [motion_light.kicad_pcb, motion_light.sch]
2018-12-02 Tune battery cover
    [motion_nightlight_housing.scad]
2018-12-03 Redo diffuser stand as lasercut part
    [motion_nightlight_housing.scad]
2018-12-23 Laser cut diffuser stand doesn't need an offset
    [motion_nightlight_housing.scad]
2018-12-23 Refine battery panel.
    [motion_nightlight_housing.scad]
2018-12-23 Add small angle to battery panel to ease opening
    [motion_nightlight_housing.scad]
2019-01-01 Add a little extra z-height to the buttons
    [motion_nightlight_housing.scad]
2019-01-05 Move various housing parts to separate files for rendering
    [housing_board_holder.scad, housing_lasercut.scad, motion_nightlight_housing.scad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]
2019-01-05 Use 100K resistor for better ambient light sensitivity
    [motion_light.kicad_pcb, motion_light.sch]
2019-01-05 It's not made of metal
    [front_grate.dxf, motion_nightlight_housing.scad]
2019-01-26 Improve ambient brightness calibration
2019-01-26 Break parts into separate .scad files
    [battery_plate.scad, board_holder.scad, diffuser.scad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]
2019-01-26 Add vertical stand
    [vertical_stand.scad]
2019-01-26 Add corner taper to help prevent plywood delamination
    [vertical_stand.scad]
2019-01-26 Add copy of boxmaker
    [boxmaker.scad]
2019-01-26 Add housing badge
2019-02-16 Update with new resistor value
    [motion_light.kicad_pcb]
2019-03-10 Make the screw pilot holes smaller
    [motion_nightlight_housing.scad]
2019-03-10 Make the button holes bigger
    [motion_nightlight_housing.scad]
2019-09-20 Update to KiCAD 5.1
    [motion_light.kicad_pcb, motion_light.sch]
2019-12-08 Clean up small mesh error
    [vertical_stand.scad]
2019-12-08 Fix small mesh error that prevented printing
    [vertical_stand.scad]
2019-12-08 Add mockup
    [mockup.scad]
2019-12-21 Tighten up inset for battery door new prints
    [motion_nightlight_housing.scad]
2019-12-29 Add link to clamps
